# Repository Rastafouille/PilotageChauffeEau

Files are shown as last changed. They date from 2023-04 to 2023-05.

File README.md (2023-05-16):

L'objectif du projet est de pouvoir piloter en puissance un appareil, ici le chauffe eau, via des requetes http.
Dans mon cas je l'utilise pour consommer le surplus de puissance généré par mes panneaux photovoltaiques et fonctionner en plus en heures creuses.

Il va falloir 
 - un ESP8266 pour se connecter au réseau, attendre les commandes http et piloter le régulateur de puissance.
 - un régulateur de tension pilotage en PWM
 - un petit transfo AC/DC 220v/5v pour alimenter l'ESP8266
 - un disjonteur de sécurité
 - un voltmétre pour connaitre la puissance réelle consommée, permettant d'ajuster la commande en fonction de la consigne
 - un petit ecran pour afficher des infos interressantes
 - voyant, connecteurs 220v et une boite. 
Tout est monté sur un rail DIN grace à des pièces imprimées en 3D (voir dossier CAD)
Cout total entre 50€ et 100€ selon recup.

Régulateur de puissance (23€)

<https://fr.aliexpress.com/item/32605706914.html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>

Carte extension NodeMcu V3 ESP8266 + carte extension (6€)

<https://fr.aliexpress.com/item/1005002104682197.html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>

Voltmètre PZEM-004T (15€)

<https://fr.aliexpress.com/item/32405328185.html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>

Ecran oled (2€)

<https://fr.aliexpress.com/item/32665981269.html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>

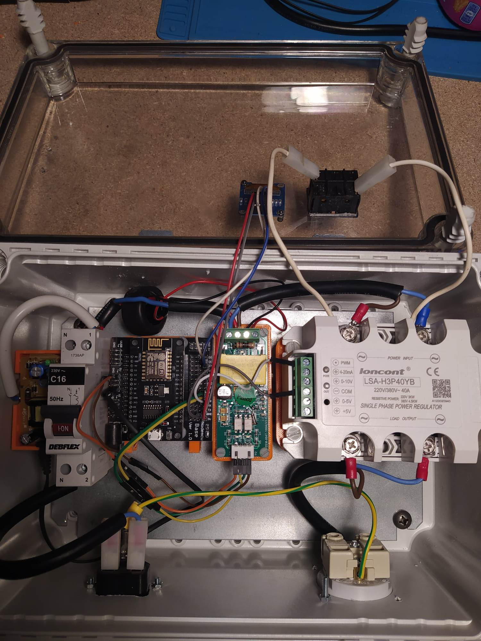
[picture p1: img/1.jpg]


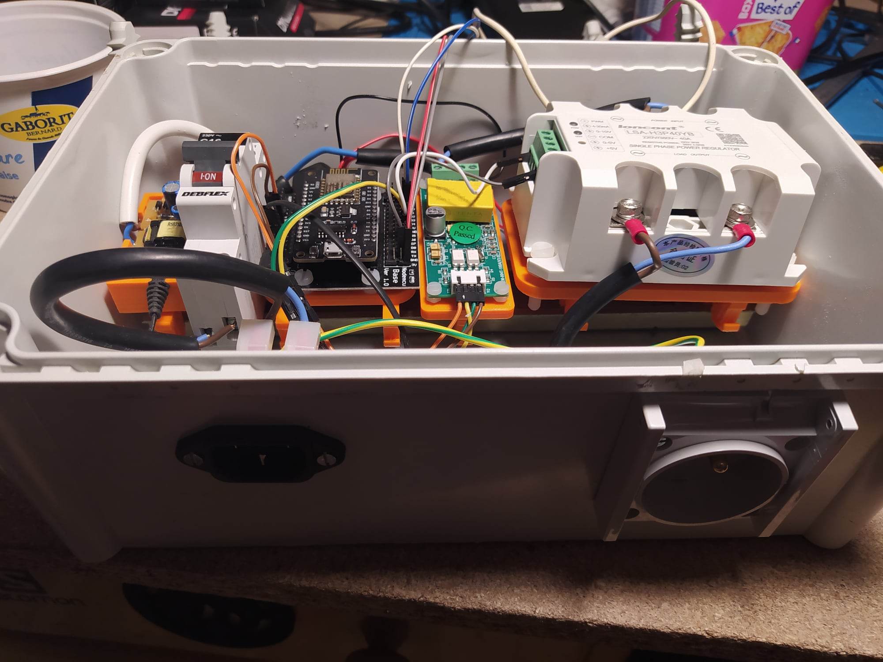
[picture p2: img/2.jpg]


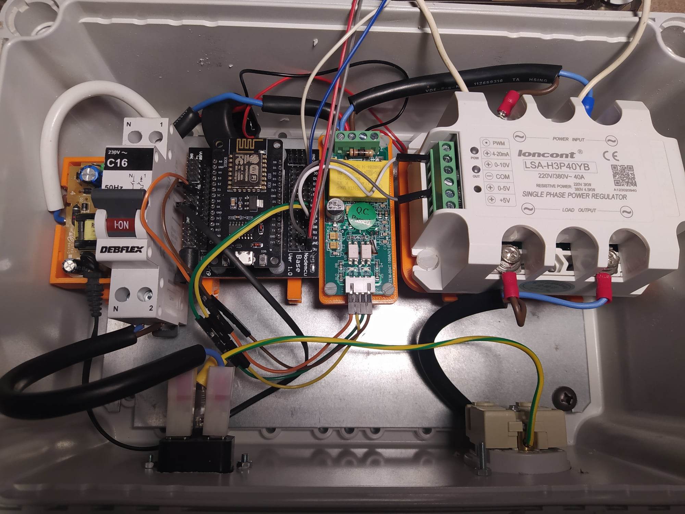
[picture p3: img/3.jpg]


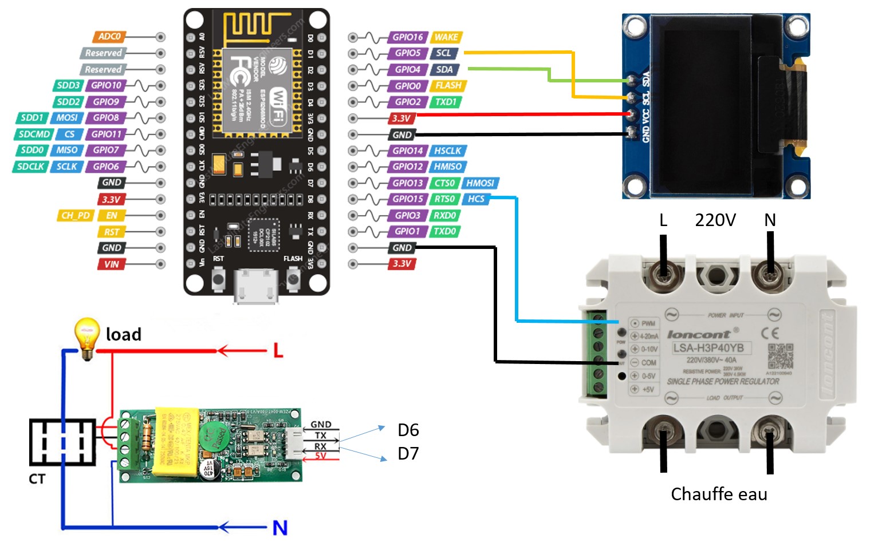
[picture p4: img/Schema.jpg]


Mise à jour 16/05/2023

Le signal PWM de l'ESP8266 sort en 3.3V alors que le régulateur attend du 4V minimum. Cela fonctionne mais pas à pleine puissance, 1000W au lieu de 3000W...
Pour régler le probléme, un petit montage transistor est necessaire. Attention ce montage inverse également le signal, facile à gerer en soft.
Voir code de l'ESP8266 modifié dans final-5v

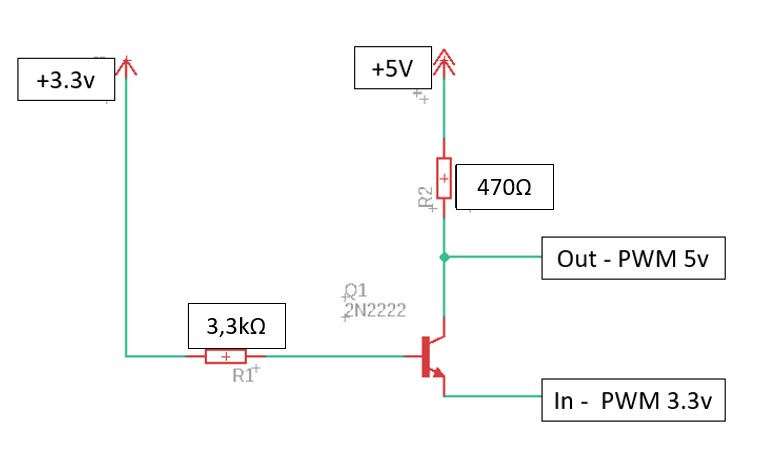
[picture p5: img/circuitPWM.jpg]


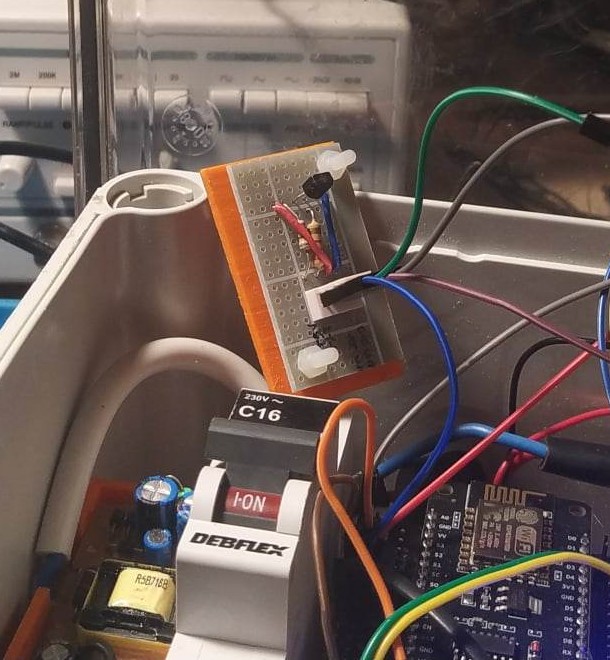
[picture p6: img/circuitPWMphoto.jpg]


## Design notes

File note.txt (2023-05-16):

probleme upload nodeMcu --> deinstaller le driver CH340 et reinstaller a partir du .exe
Probleme connexio arduino nano --> board 328P pas nano

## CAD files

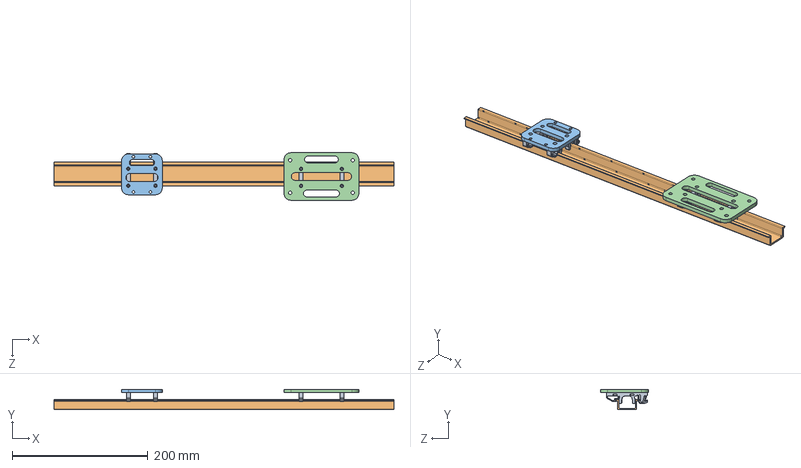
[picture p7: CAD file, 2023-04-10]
CAD/Assemblage1.SLDASM
500.0 x 30.0 x 70.0 mm
DIN_Rail_clip x 4
RailDIN
PlaqueESP8266
PlaqueRegulateur

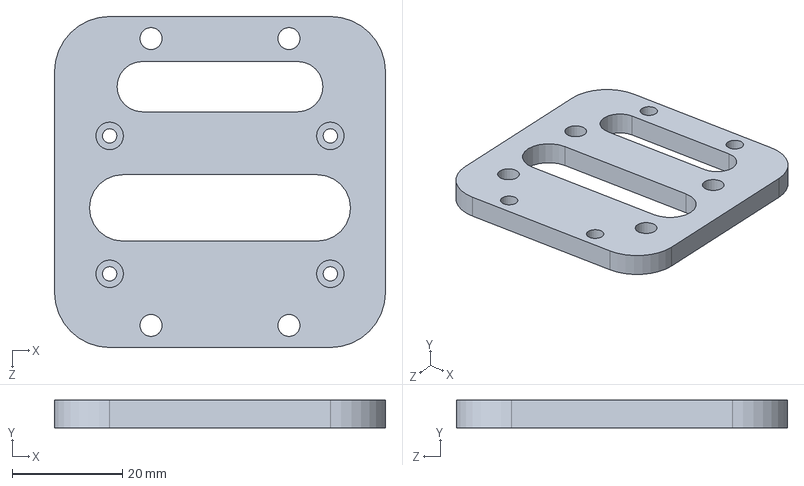
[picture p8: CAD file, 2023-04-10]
CAD/PlaqueESP8266.SLDPRT
60.0 x 5.00 x 60.0 mm

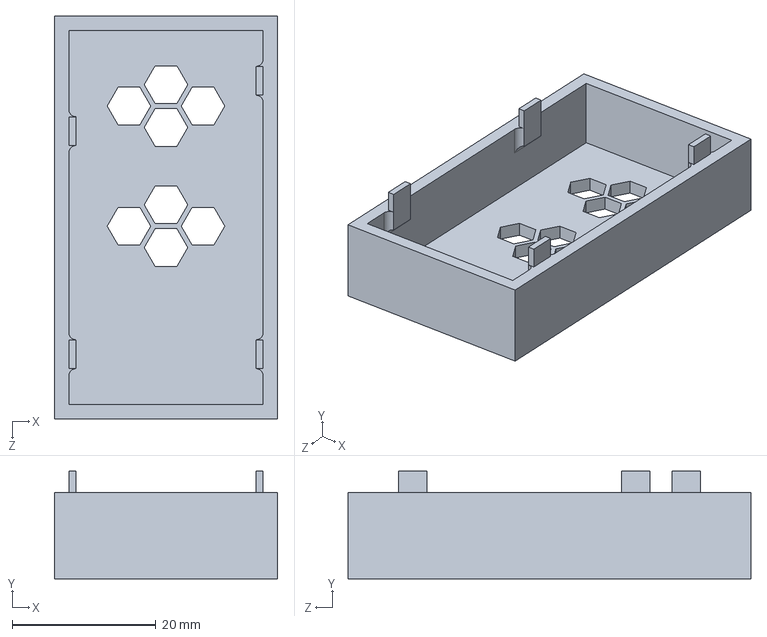
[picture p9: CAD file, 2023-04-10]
CAD/CapotTransfo5V.SLDPRT
31.0 x 15.0 x 56.0 mm

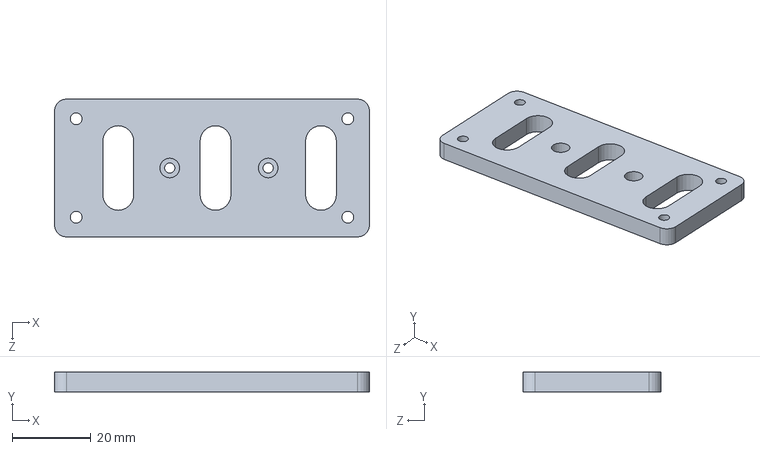
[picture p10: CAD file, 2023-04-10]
CAD/PlaquePZEM.SLDPRT
80.0 x 5.00 x 35.0 mm

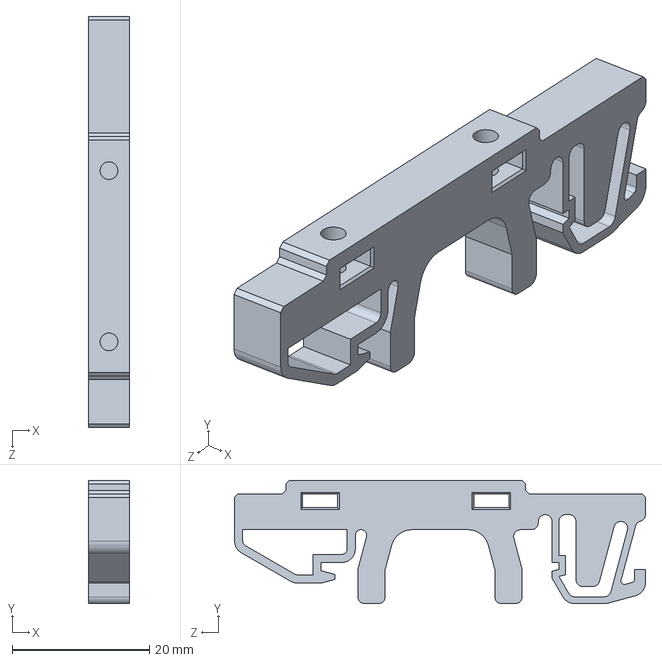
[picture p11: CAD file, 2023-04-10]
CAD/DIN_Rail_clipv2.SLDPRT
6.00 x 18.0 x 60.0 mm

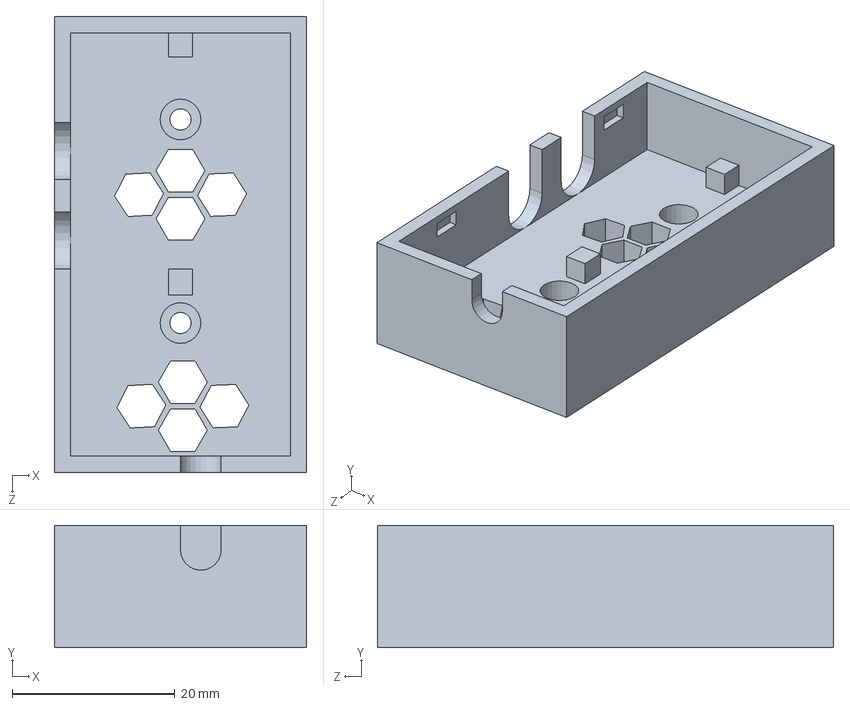
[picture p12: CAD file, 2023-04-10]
CAD/PlaqueTransfo5V.SLDPRT
31.0 x 15.0 x 56.0 mm

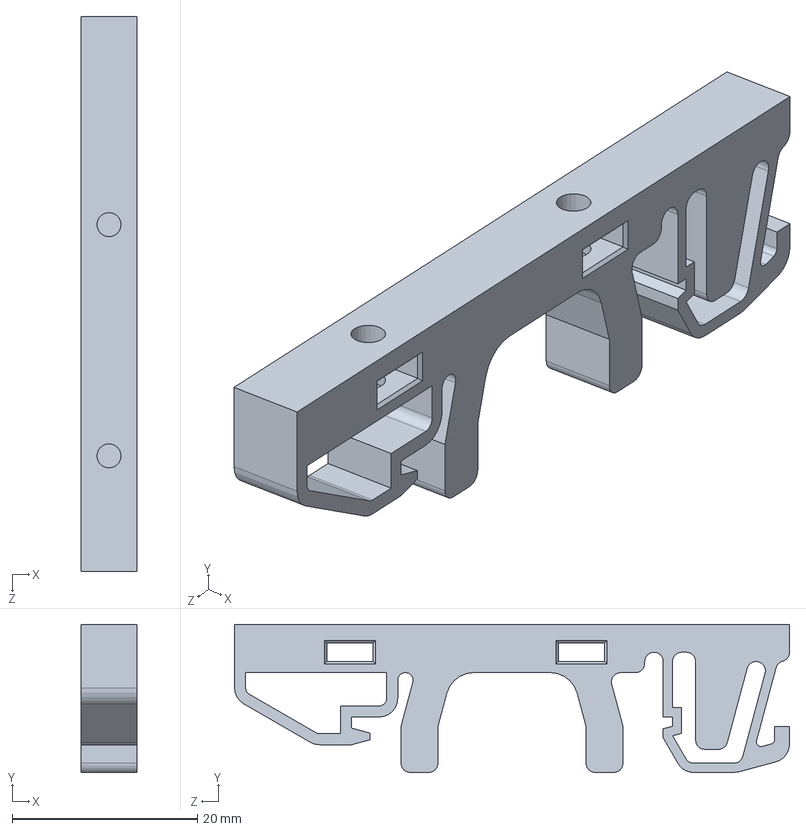
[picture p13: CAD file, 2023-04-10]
CAD/DIN_Rail_clip.SLDPRT
6.00 x 16.0 x 60.0 mm

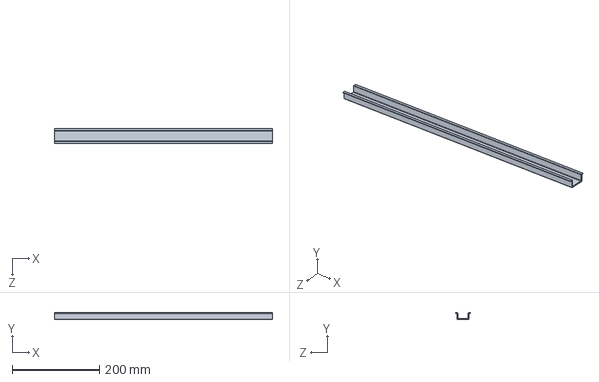
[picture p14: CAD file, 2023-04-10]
CAD/RailDIN.SLDPRT
500.0 x 15.0 x 35.0 mm

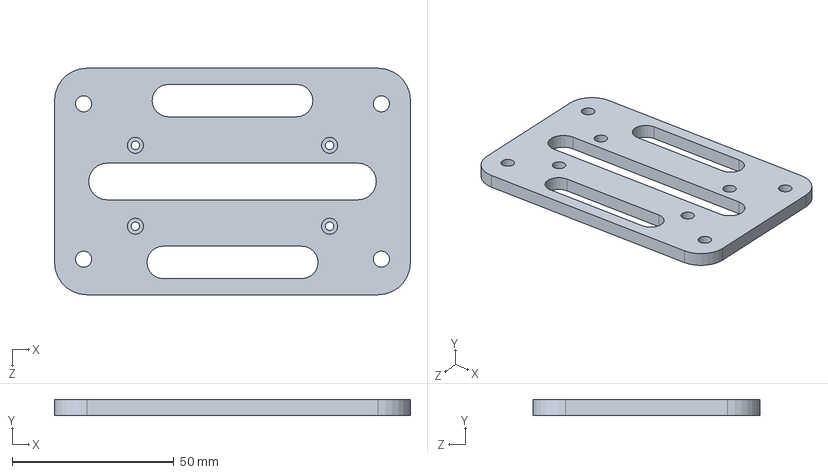
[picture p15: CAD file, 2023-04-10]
CAD/PlaqueRegulateur.SLDPRT
110.0 x 5.00 x 70.0 mm

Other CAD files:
CAD/CapotTransfo5V.STL
CAD/DIN_Rail_clip.STL
CAD/DIN_Rail_clipv2.STL
CAD/PlaqueESP8266.STL
CAD/PlaquePZEM.STL
CAD/PlaqueRegulateur.STL

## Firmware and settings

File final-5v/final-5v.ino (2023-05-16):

#include <Wire.h>
#include <Adafruit_GFX.h>
#include <Adafruit_SSD1306.h>


// Variable pour l'écran OLED connectée en I2C (SDA, SCL pins)
#define SCREEN_WIDTH 128 // OLED display width, in pixels
#define SCREEN_HEIGHT 64 // OLED display height, in pixels
Adafruit_SSD1306 display(SCREEN_WIDTH, SCREEN_HEIGHT, &Wire, -1);


// Bibliotheque ESP8266
#include <ESP8266WiFi.h>
#include <ESP8266WebServer.h>

// paramètres de connection au wifi local
const char* ssid = "XXX";  // Enter SSID here
const char* password = "XXX";  //Enter Password here

ESP8266WebServer server(80);

//"server.arg("consigne");".
//http://192.168.1.48/set?consigne=255

// variable pour le pilotage en puissance. la consigne est la valeur de puissance demandée, et la commande la valeur entre 0 et 255 de pilotage du régulateur
// un étalonnage est necessaire pour connaitre le lien entre les deux
String st = "";
unsigned int myConsigne = 0;
float commande = 255.0;
float ecart = 0.0;

// pin PWM de pilotage du régulateur de tension
const int PinPWM = 15; 


// Paramétrage voltmètre
// permet de connaitre la valeur de puissance réelle instantanée
#include <PZEM004Tv30.h>
#include <SoftwareSerial.h>
/* Use software serial for the PZEM
 * Pin 12 Rx (Connects to the Tx pin on the PZEM) --> D6
 * Pin 13 Tx (Connects to the Rx pin on the PZEM)  --> D7
*/
#if !defined(PZEM_RX_PIN) && !defined(PZEM_TX_PIN)
#define PZEM_RX_PIN 12
#define PZEM_TX_PIN 13
#endif
SoftwareSerial pzemSWSerial(PZEM_RX_PIN, PZEM_TX_PIN);
PZEM004Tv30 pzem(pzemSWSerial);
float voltage = 0.0;
float current = 0.0;
float power = 0.0;

void setup() {
  Serial.begin(115200);
  delay(100);

  if(!display.begin(SSD1306_SWITCHCAPVCC, 0x3C)) { // Address 0x3D for 128x64
    Serial.println(F("SSD1306 allocation failed"));
    for(;;);
  }
  delay(2000);
  display.clearDisplay();

  display.setTextSize(1);
  display.setTextColor(WHITE);
  display.setCursor(0, 10);

  display.print("Connecting to ");  display.println(ssid);  display.display(); 

  //connect to your local wi-fi network
  WiFi.begin(ssid, password);

  //check wi-fi is connected to wi-fi network
  while (WiFi.status() != WL_CONNECTED) {
  delay(1000);
  }
  display.print("IP  ");  display.println(WiFi.localIP());  display.display(); 


  server.on("/set", handle_Set);
  server.on("/update", handle_Update);
  server.onNotFound(handle_NotFound);

  server.begin();
  display.println("HTTP server started");  display.display(); 

  analogWrite(PinPWM, 255);
  
}
void loop() {
  server.handleClient();

//   // Read the data from the sensor
   voltage = pzem.voltage();
   current = pzem.current();
   power = pzem.power();

  display.clearDisplay();
  display.setTextSize(1);
  display.setTextColor(WHITE);
  display.setCursor(0, 10);
  display.print("Connected to ");  display.println(ssid);  display.display(); 
  display.print("IP  ");  display.println(WiFi.localIP());  display.display();
  display.print("Consigne : ");  display.print(myConsigne); display.println("W"); display.display();
  display.print("Commande : ");  display.println(commande); display.display(); 
  display.print("Puissance : ");  display.print(power); display.print("W");display.display(); 


// Pilotage du régulateur de tension
 ecart=myConsigne-power;
 if (ecart > 20)
  {commande-=2;} 
 if (ecart < -20)
  {commande+=2;} 
 if (commande > 214) // valeurs a etalonner
  {commande=255;}
 if (commande < 0)
  {commande=0;}
 analogWrite(PinPWM, commande);
 delay(2000);
}

// si une consigne de puissance est récue
void handle_Set() {
  st = server.arg("consigne");
  myConsigne = st.toInt();
  commande=int((3000-myConsigne)/14); // valeurs a etalonner
  analogWrite(PinPWM, commande);
  //server.send(200, "text/plain", String (myConsigne));
  server.send(200, "text/plain", "");
}

// si une demande de retour puissance est demandée
void handle_Update() {
  server.send(200, "text/plain", String (power));
}

void handle_NotFound(){
  server.send(404, "text/plain", "Not found");
}
